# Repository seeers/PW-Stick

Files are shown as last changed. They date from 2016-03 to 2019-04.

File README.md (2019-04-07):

**[PW-Stick](https://github.com/seeers/PW-Stick)** is a easy to use hardware password manager
======

## Features
* Stores up to 9 user names and passwords / each up to 47 characters
* Keepass 2 (http://keepass.info/) supports the PW-Stick with a plugin
* AES Encrypted Memory
* Protected by a 4 digit pin
* Secure erase after 4 wrong pin attempts
* Optional auto lock timer
* Works as HID Keyboard

## Portable version
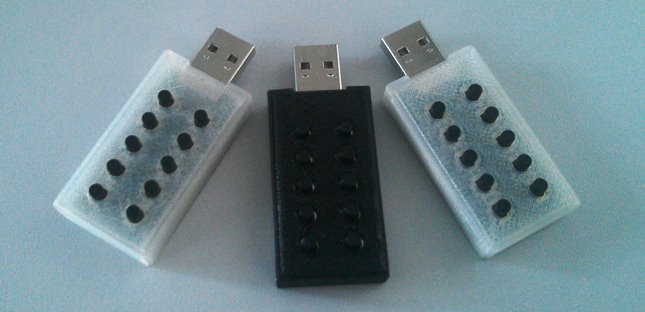
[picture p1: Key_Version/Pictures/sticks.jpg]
Stick


## Desktop version
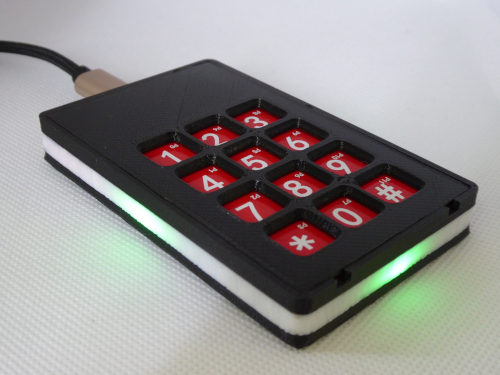
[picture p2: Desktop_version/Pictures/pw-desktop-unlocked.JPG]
Desktop


## Instructions

See the wiki for build and use instructions.

## Notes
**Released:** 
* Stick version by Seeers : Mar 23, 2016
* Desktop version by MatthGyver : Apr 07, 2019

**Status:** Operational, maybe some bugs, works for me since some months.

**Licence:**  CC BY-NC-SA 3.0

## Contact
**Point of Contact:**  
* Twitter: [@seeers0](https://twitter.com/seeers0)
* E-Mail: <seeers@gmx.de>

-----

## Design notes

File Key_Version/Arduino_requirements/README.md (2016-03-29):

## Arduino Version:
* arduino-1.0.5-r2

## Used Libraries:
* https://github.com/DavyLandman/AESLib
* https://github.com/adafruit/Adafruit_NeoPixel
* http://playground.arduino.cc/Code/Password

## Modified files
* \Arduino-1.0.5-r2\hardware\arduino\cores\arduino\HID.cpp
* \Arduino-1.0.5-r2\hardware\arduino\cores\arduino\USBAPI.h
* \Arduino-1.0.5-r2\hardware\arduino\cores\arduino\USBCore.h

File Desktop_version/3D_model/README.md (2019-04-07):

# Description
Bottom is composed of 3 pieces :
* bottom-a.stl
* bottom-b.stl
* bottom-c.stl

All this part are assembled in one with Slic3r as bottom.amf file.

I'm using a dual head printer but you should be able to do this with single head. There is some technics to change filament like [this](https://www.youtube.com/watch?v=vnbQ0YTZnmk). *I've not tested*

# Pictures
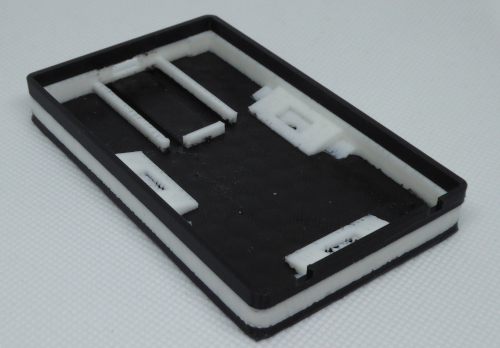
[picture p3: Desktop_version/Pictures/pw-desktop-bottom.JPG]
Bottom


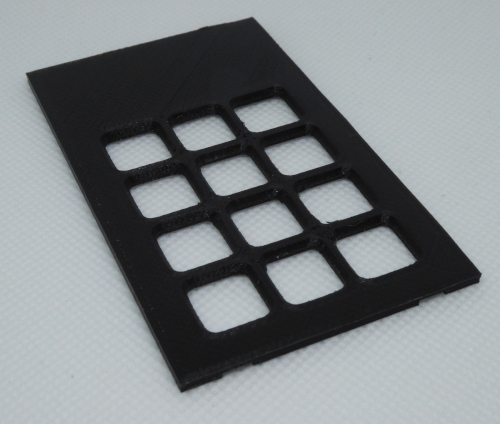
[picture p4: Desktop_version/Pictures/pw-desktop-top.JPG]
Top


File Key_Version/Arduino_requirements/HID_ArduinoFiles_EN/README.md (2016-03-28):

## Location:
**path_to_arduino**\Arduino-1.0.5-r2\hardware\arduino\cores\arduino

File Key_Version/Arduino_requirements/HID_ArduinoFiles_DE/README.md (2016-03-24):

## Location:
**path_to_arduino**\Arduino-1.0.5-r2\hardware\arduino\cores\arduino

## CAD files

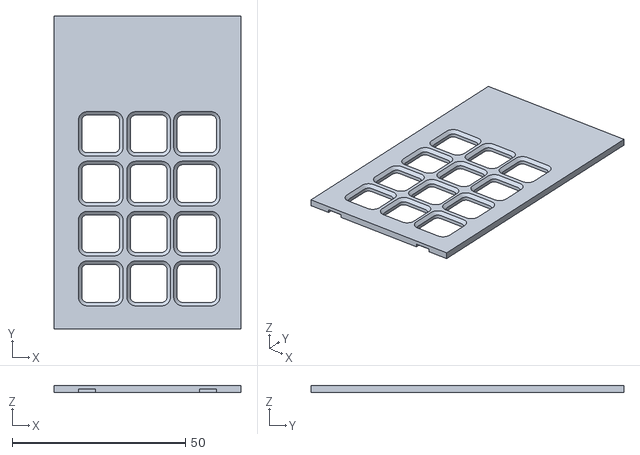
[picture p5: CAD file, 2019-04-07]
Desktop_version/3D_model/top.STL
53.9 x 90.2 x 2.10

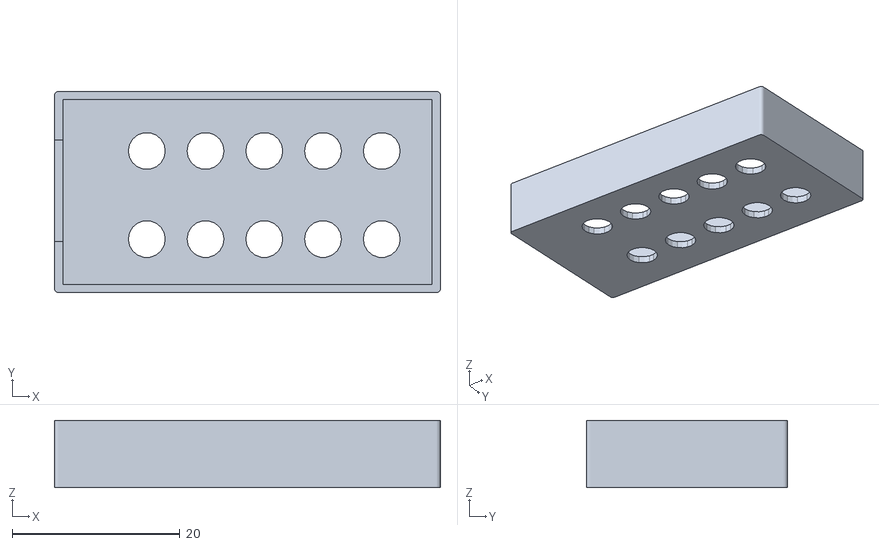
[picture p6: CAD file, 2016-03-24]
Key_Version/3D_PrintedCase/PW_Stick_top.stl
46.0 x 24.0 x 8.00

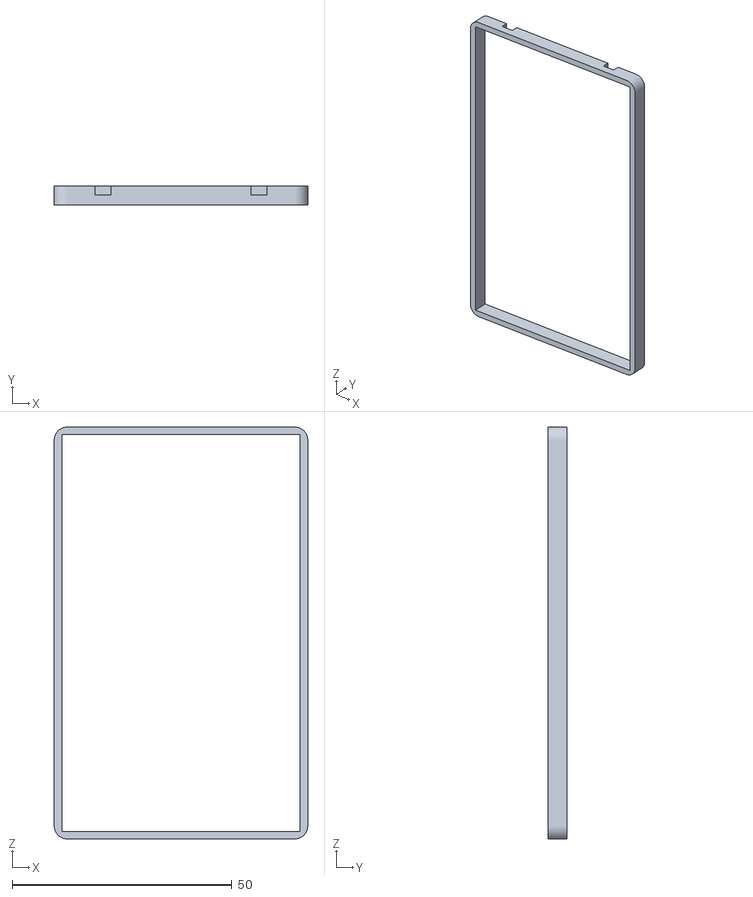
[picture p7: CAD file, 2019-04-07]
Desktop_version/3D_model/bottom-c.STL
57.7 x 4.30 x 93.8

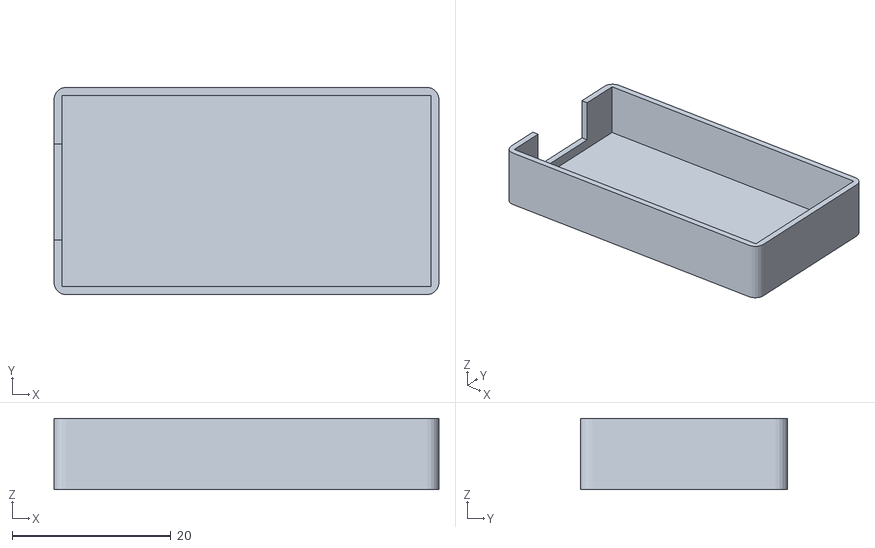
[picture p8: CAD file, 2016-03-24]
Key_Version/3D_PrintedCase/PW_Stick_bottom.stl
48.5 x 26.1 x 9.00

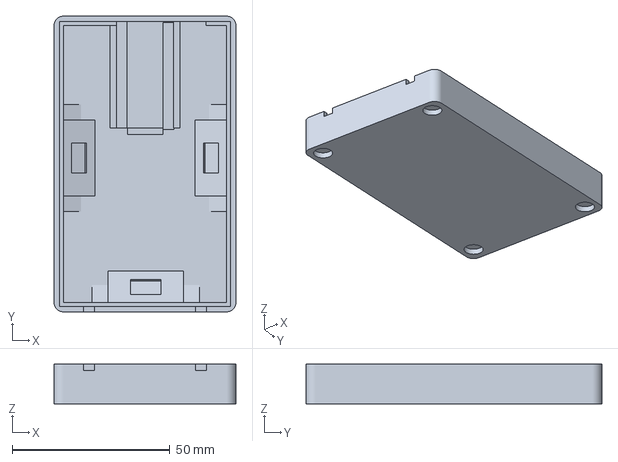
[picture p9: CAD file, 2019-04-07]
Desktop_version/3D_model/bottom.amf
57.7 x 93.8 x 12.6 mm

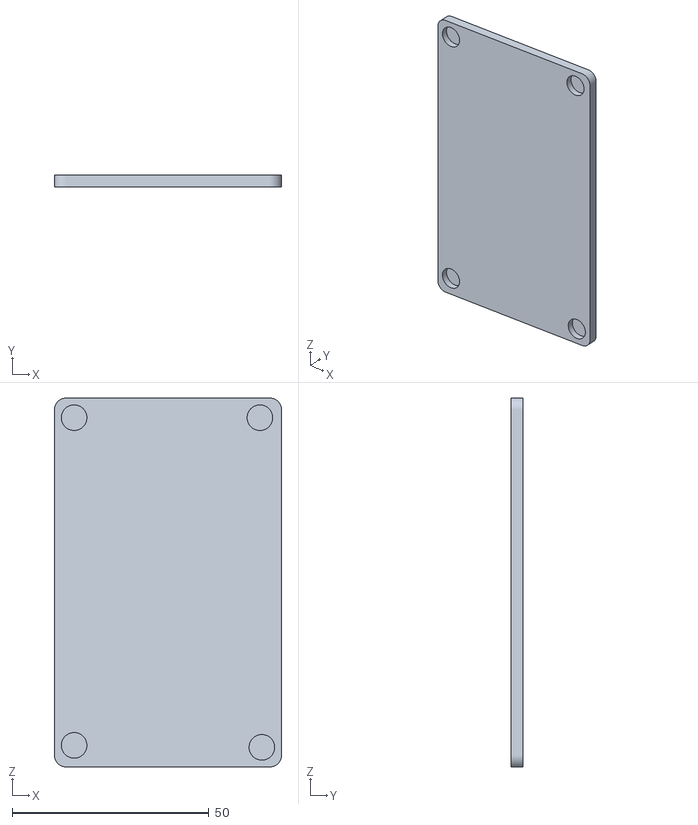
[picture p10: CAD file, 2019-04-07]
Desktop_version/3D_model/bottom-a.STL
57.7 x 3.00 x 93.8

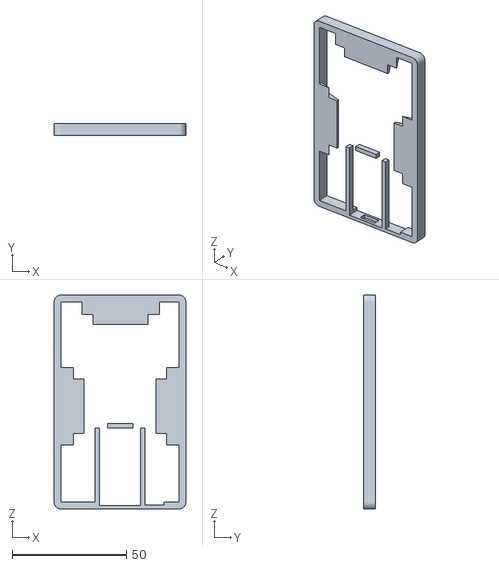
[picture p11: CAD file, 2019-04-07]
Desktop_version/3D_model/bottom-b.STL
57.7 x 5.40 x 93.8

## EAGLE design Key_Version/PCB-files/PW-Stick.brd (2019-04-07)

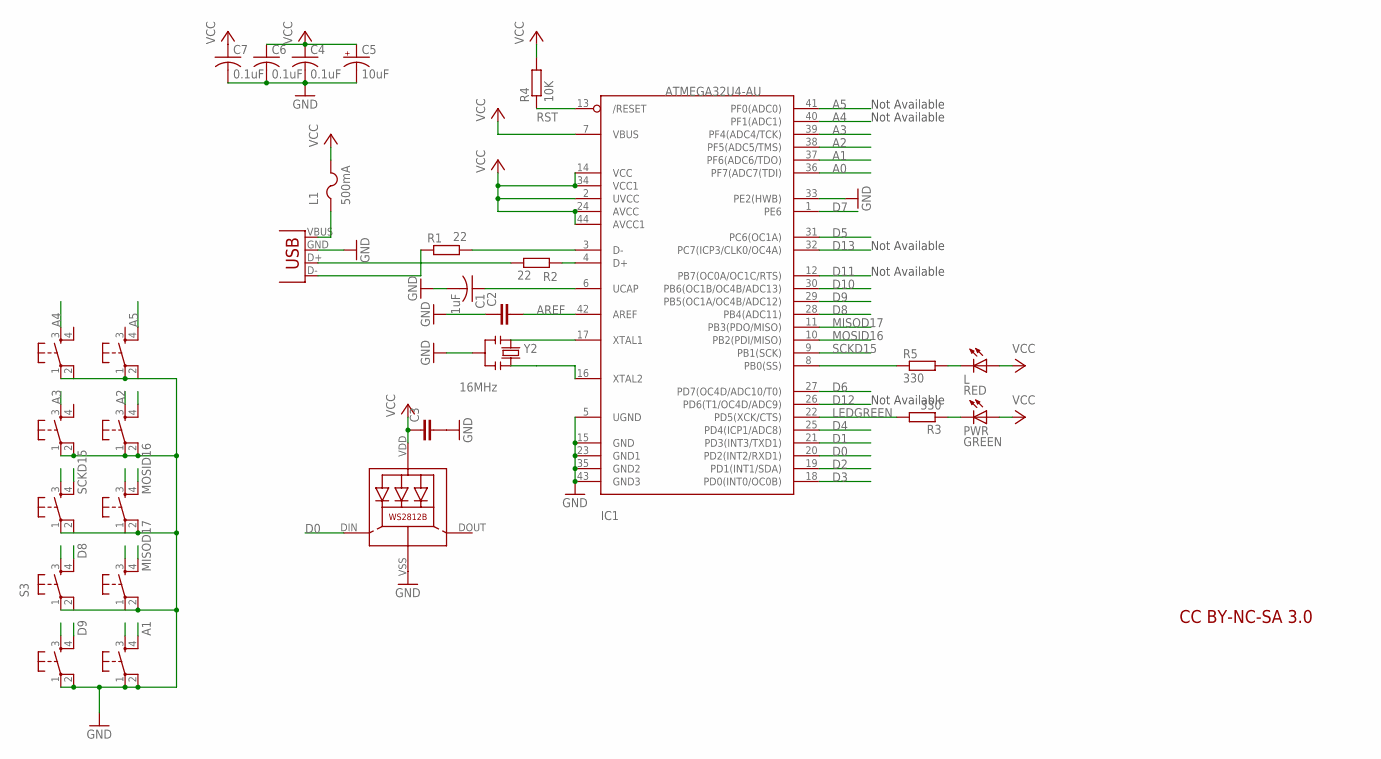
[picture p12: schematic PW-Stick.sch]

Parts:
C1: 1uF; C0805K
C2, C3: C-EUC0805; C0805
C4, C6, C7: 0.1uF; C0805K
C5: 10uF; A/3216-18R
IC1: ATMEGA32U4-AU; TQFP44
JP2: USB-A-H
L: RED; CHIPLED_0805
L1: 500mA; R1206
LED1: WS2812B
PWR: GREEN; CHIPLED_0805
R1, R2: 22; R0805
R3, R5: 330; R0805
R4: 10K; R0805
S1, S2, S3, S4, S5, S6, S7, S8, S9, S10: DTSM-6
Y2: 16MHz; RESONATOR

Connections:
A0: IC1.36 (PF7(ADC7(TDI))
A1: IC1.37 (PF6(ADC6/TDO)), S2.4
A2: IC1.38 (PF5(ADC5/TMS)), S8.3
A3: IC1.39 (PF4(ADC4/TCK)), S7.3
A4: IC1.40 (PF1(ADC1)), S9.3
A5: IC1.41 (PF0(ADC0)), S10.4
AREF: C2.2, IC1.42 (AREF)
D0: IC1.20 (PD2(INT2/RXD1)), LED1.DIN (DI)
D1: IC1.21 (PD3(INT3/TXD1))
D2: IC1.19 (PD1(INT1/SDA))
D3: IC1.18 (PD0(INT0/OC0B))
D4: IC1.25 (PD4(ICP1/ADC8))
D5: IC1.31 (PC6(OC1A))
D6: IC1.27 (PD7(OC4D/ADC10/T0))
D7: IC1.1 (PE6)
D8: IC1.28 (PB4(ADC11)), S3.4
D9: IC1.29 (PB5(OC1A/OC4B/ADC12)), S1.4
D10: IC1.30 (PB6(OC1B/OC4B/ADC13))
D11: IC1.12 (PB7(OC0A/OC1C/RTS))
D12: IC1.26 (PD6(T1/OC4D/ADC9))
D13: IC1.32 (PC7(ICP3/CLK0/OC4A))
GND: C1.2, C2.1, C3.2, C4.2, C5.-, C6.2, C7.2, IC1.5 (UGND), IC1.15 (GND), IC1.23 (GND1), IC1.33 (PE2(HWB)), IC1.35 (GND2), IC1.43 (GND3), JP2.GND (VBUS), LED1.VSS (GND), S1.1, S1.2, S2.1, S2.2, S3.1, S4.2, S5.1, S6.2, S7.1, S7.2, S8.1, S8.2, S9.1, S10.1, Y2.2
LEDGREEN: IC1.22 (PD5(XCK/CTS)), R3.2
MISOD17: IC1.11 (PB3(PDO/MISO)), S4.4
MOSID16: IC1.10 (PB2(PDI/MISO)), S6.3
unnamed: PWR.C, R3.1
unnamed: JP2.D+ (D-), R2.1
unnamed: IC1.3 (D-), R1.2
unnamed: IC1.4 (D+), R2.2
unnamed: JP2.D- (D+), R1.1
unnamed: IC1.8 (PB0(SS)), R5.1
unnamed: L.C, R5.2
unnamed: IC1.17 (XTAL1), Y2.1
unnamed: IC1.16 (XTAL2), Y2.3
unnamed: C1.1, IC1.6 (UCAP)
RST: IC1.13 (/RESET), R4.1
SCKD15: IC1.9 (PB1(SCK)), S5.3
VBUS: JP2.VBUS (GND), L1.1
VCC: C3.1, C4.1, C5.+, C6.1, C7.1, IC1.2 (UVCC), IC1.7 (VBUS), IC1.14 (VCC), IC1.24 (AVCC), IC1.34 (VCC1), IC1.44 (AVCC1), L.A, L1.2, LED1.VDD, PWR.A, R4.2

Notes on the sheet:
CC BY-NC-SA 3.0
Not Available

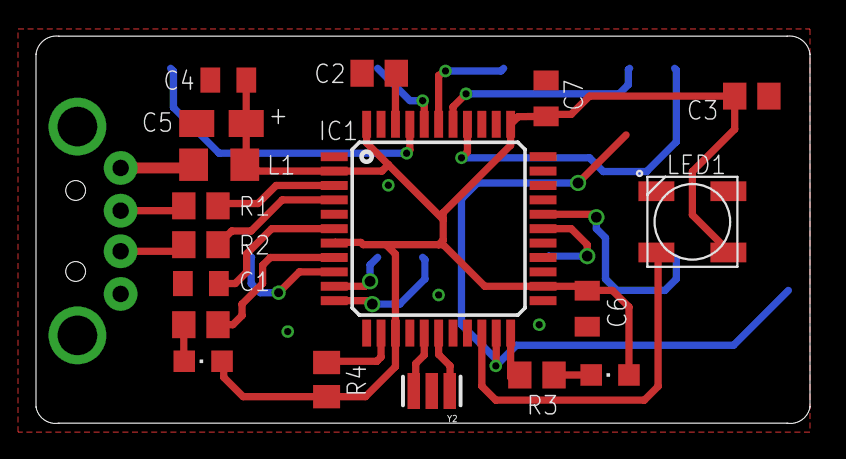
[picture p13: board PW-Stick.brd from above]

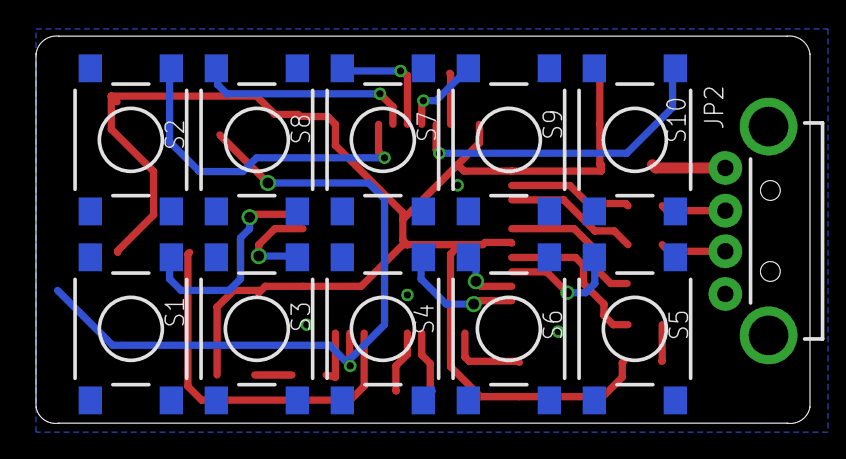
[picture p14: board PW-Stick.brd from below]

Board: 2 copper layers, 43.0 x 21.5 mm, 29 parts (11 on the bottom side), 27 nets.

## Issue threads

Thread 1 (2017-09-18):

[Request]Schematic source file

matthgyver, 2017-09-18:
Hi,

Your project seem very interresting.
I just buy an Arduino Leonardo to try it but I plan to build one from scratch.
Could you publish the source of the electronic schematic and / or the PCB layer please ?

Thank you

seeers, 2017-09-20:
Hi,
yes of course:
[PW-StickPublic.zip](https://github.com/seeers/PW-Stick/files/1318209/PW-StickPublic.zip)

matthgyver, 2017-09-20:
Hi,
Thank you very much.
I see that there is no value for C2 and C3. What do you recommend please ?
On the way, where did you get your printed circuit boards ?

seeers, 2017-09-20:
You're welcome. C2 and C3 are 100n
I got my Boards from https://www.itead.cc/open-pcb/pcb-prototyping.html

matthgyver, 2017-09-20:
Price look good and the finish too when I see your pictures.
What is the height of your microswitch to go with the 3D printed case please  ? (I prepare my shopping list)

matthgyver, 2017-12-29:
I've take this one : https://fr.aliexpress.com/item/Free-Shipping-100pcs-Tact-Switch-DIP-type-6x6X8-mm-Tactile-Switch/866454082.html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
It's 6x6x8mm and fit nice

Closed 2017-12-29.

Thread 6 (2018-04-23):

AESLib related IDE error

tinker4545, 2018-04-23:
Thx seers for your work, i have a problem, im getting error codes relating to AESLib (see below)
Ive tried arduino 1.0.4 aswell as 1.0.5-r2.
What is the 'HardwarePWManager.v12.suo' ? do i need to do anything with this file?
Many thanks

Documents\Arduino\libraries\AESLib\AESLib.c: In function 'aes128_enc_multiple':
Documents\Arduino\libraries\AESLib\AESLib.c:75: error: 'for' loop initial declaration used outside C99 mode
\Documents\Arduino\libraries\AESLib\AESLib.c: In function 'aes256_enc_multiple':
\Documents\Arduino\libraries\AESLib\AESLib.c:95: error: 'for' loop initial declaration used outside C99 mode
\Documents\Arduino\libraries\AESLib\AESLib.c: In function 'aes128_dec_multiple':
Documents\Arduino\libraries\AESLib\AESLib.c:213: error: 'for' loop initial declaration used outside C99 mode
Documents\Arduino\libraries\AESLib\AESLib.c: In function 'aes256_dec_multiple':
\Documents\Arduino\libraries\AESLib\AESLib.c:233: error: 'for' loop initial declaration used outside C99 mode

matt i moved it over to here, cheers

matthgyver, 2018-04-23:
Hi,
I've problem with Arduino version > 1.0.5 but it's not the same (error on keyboard.h).
I've not this error but I'm on Linux and the compiler or compilation setting are maybe different.
Try to modifiy de lib file like as described here : https://stackoverflow.com/questions/24881/how-do-i-fix-for-loop-initial-declaration-used-outside-c99-mode-gcc-error
(Extract the i variable declaration from the loop)

For the suo file, google give me the response : https://fileinfo.com/extension/suo

tinker4545, 2018-04-23:
matt ur a star! i followed the links and finally got it to compile :-) I edited the .h file :-) 1st time doing it lol

another question for you if you dont mind, im putting together seers prototype version using a full pro micro, looking at the schematic i will need other components, can you tell what ones I need? I got the buttons soldered and ready and the WS2812b is in the mail.

matthgyver, 2018-04-23:
You just need buttons and WS2812b.
Take a look into the "desktop version" folder. I'm using only a full pro micro, switch and LED.
Source code is for the final version so you'll modify it for define PIN correctly I think.
Schematic is for building from scratch.

tinker4545, 2018-04-23:
ah i see, no wonder i was confused a little, makes sense now. il look at the desktop version later.

thanks again for your help (i was gonna give up this project)

matthgyver, 2018-04-24:
You'r welcome

Closed 2018-04-24.

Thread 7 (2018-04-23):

Arduino requirement question

matthgyver, 2018-04-23:
Hi Seeers,

I'm trying to update your code to do a project for [PlateformIO](https://platformio.org/).
This IDE is free, light and powerfull.
It use a latest version of Arduino core so I should update this files :
- USBAPI.h
- USBCore.cpp

Since your work, lot of thing have changed.
Did you remember the adaptation that you made ? It help me to update the code.

Thank you

Closed 2018-09-11.

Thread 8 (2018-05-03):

UK keyboard layout

tinker4545, 2018-05-03:
Hi Seers,
Can you help me out with a small problem, i got everything running but the keyboard layout is US i need a UK layout, ive been trying to change it in the HID.cpp but got all mixed up, is there a way to change it all at once?
Thanks,  great project btw

matthgyver, 2019-05-11:
Hi Tinker,

Keyboard layout on Arduino is'nt simple :-/ There's no library like the Teensy board have by exemple.

I needed French Azerty layout and don't found anything working great so I build my own : https://github.com/matthgyver/Arduino-Keyboard-FR

Maybe you could build your own. This link helped me :
* https://raw.githubusercontent.com/qlyoung/armory-keyboard/master/layouts/keyboard-layout.png
* https://www.ascii-code.com/

Closed 2019-05-11.

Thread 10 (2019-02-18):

Plugins problems with linux ( keepass 2.38 ) + pinout misunderstood

Debian-10, 2019-02-18:
Hello and thanks again for providing this github !

I installed Keepass 2.38 with ubuntu repositories ( it uses mono ). I copied the PWstick.dll plugin into the correct path. When i restart KeePass , i have " non compatible plugin ". The thing I don't understand is that it works like a charm on windows with the same keepass version. I installed mono-complete. Any ideas ?

When reading the .ino code , I don't understand where is A5 pin and strange that you can only have 8 buttons ( most strange fact is that they're soldered by two ports and not like casual : to port and to GND )
That's maybe not best explaination ( I'm French :D )

Debian-10

Debian-10, 2019-05-09:
After reading more the code and searched more about arduino, i found solution for buttons.

matthgyver, 2019-05-11:
Salut,

Désolé de ne pas avoir répondu, je ne reçois pas de notifications sur les issues (faut que je regarde de plus près).

Pour Mono je ne peux pas te répondre, je n'ai pas testé. J'aimerais une solution plus universelle que Keepass car çle plugin ne fonctionne que sous windows mais je n'ai pas les connaissances pour développer quelque chose :-/

Concernant le cablage je n'ai pas bien saisi ce que tu veux dire désolé.

Closed 2019-05-09.

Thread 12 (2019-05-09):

Problem with the plugin on windows

Debian-10, 2019-05-09:
Hello again,
As i'm still trying to get this working, i successfully burned the code into my arduino pro-micro.
I have keepass 2.41 installed on my computer and put the pwkeeper.dll plugin in the plugin/ folder.
I connect it to windows, I type the default password ' 0000 ' and unlocked the key but when trying to change settings of the key or reading its data, i always have ' No key found '.
when i press "0" button on my key, it locks the computer like it should do.
I precise that i already tried on another computer.
Thanks again for this recent update !

Debian-10

tinker4545, 2019-05-09:
The Plugin is compiled for KeePass 2.32

Debian-10, 2019-05-10:
> The Plugin is compiled for KeePass 2.32

Regarding the wiki , the plugin works on 2.41 too.

tinker4545, 2019-05-10:
Ah ur right im on the old version, try 2.32 anyways just to see

Debian-10, 2019-05-11:
What is your version of keepass when the plugin work for you ?

matthgyver, 2019-05-11:
Hi,

It's work with the last version of Keepass (a friend have tested recently).

Have you installed the Arduino IDE on your windows ? It act as a "driver" and it's needed to configure the stick with Keepass. *(only for configure it, you can use it on any computer without IDE)*

What version did you use ? (stik or desktop)

Debian-10, 2019-05-11:
Hello, i have the arduino ide on my computer.
The most strange fact is that i tested the key month ago and it worked but now not . ( Even with same arduino version and same keepass )

Debian-10, 2019-05-11:
I don't understand at all , i previously reinstalled the arduino ide but i did it now again and it works. But for how many time ?

tinker4545, 2019-05-11:
> s

2.32   anyways glad u got it working

matthgyver, 2019-05-12:
Strange. Maybe due to system update.

Debian-10, 2019-05-12:
So now , if I want to connect my key with keepass on another computer, should I install arduino on it ?

matthgyver, 2019-05-12:
Yes.
Arduino IDE contain a driver that allow serial communication between computer and Arduino.
Maybe driver installation (https://www.arduino.cc/en/Guide/DriverInstallation) is enougth. I have'nt tested.

Debian-10, 2019-05-12:
Thanks a lot for help !

Closed 2019-05-12.

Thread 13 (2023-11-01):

BOM in file

LoriVinyls, 2023-11-01:
Hello!

In BOM file no detailed specifications about each resistor\capacitor. I went to shop and they say i need to be more detail because with same resistance\capacitys there are few options to choose with different Watt's

Thank you

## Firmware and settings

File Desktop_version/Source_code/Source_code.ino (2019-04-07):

/*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
 Commercial use of this project is not allowed
 	
 Contact: seeers@gmx.de
 Desktop & Touch version : MatthGyver
  
 You need an old Arduino IDE because the keyboard emulation was different.
 With the recent Arduino, keyboard is'nt into the core and all library that
 I've tested don't support extended ASCII so don't work well for other langage that US.
 Original core code was modified by Seers to support them but only work with old Arduino vesion.

 Used Libraries:
 https://github.com/DavyLandman/AESLib
 https://github.com/adafruit/Adafruit_NeoPixel
 http://playground.arduino.cc/Code/Password
 https://bitbucket.org/teckel12/arduino-toneac/wiki/Home
 https://github.com/adafruit/Adafruit_MPR121


Buzzer connection like in the library documentation : pin 9 & 10
Keypad connection is in 2IC so :
  - SDA = Pin digital 2
  - SCL = Pin digital 3
  - IRQ = Not connected
 */

#include "cButton.h"
#include "Wire.h"
#include <EEPROM.h>
#include <Password.h>
#include "EEPROMAnything.h"
#include <Adafruit_NeoPixel.h>
#include <AESLib.h>
#include "Adafruit_MPR121.h"
#include <toneAC.h>

// #define DEBUG

// If you want that the device is unlock at start (usefull for tests)
#define LOCKED  'true'

// If DEVMODE = true, AES key is'nt regenerated so stored data is reachable after new burn
#define DEVMODE 'false'

// ----------------------------------------------------------------------------
// Set keyboard layout
// ----------------------------------------------------------------------------

// #define KEYBOARD_LAYOUT 'US'
#define KEYBOARD_LAYOUT 'FR'

#if KEYBOARD_LAYOUT == 'FR'
#include <KeyboardFR.h>
#else
#include <Keyboard.h>
#endif
// ----------------------------------------------------------------------------

#define LED_PIN                   5    //LED
#define NUM_LED                   3    //Number of LED

#define DEFAULT_LONGPRESS_LEN    25  // Min nr of loops for a long press
#define DELAY                    20  // Delay per loop in ms - orig 20

#define buttoncount				10

//////////////////////////////////////////////////////////////////////////////
//EEPROM
#define Get_All_EEPROM        0x40  
#define WriteACC1             0x41  
#define WriteACC2             0x42   
#define WriteACC3             0x43   
#define WriteACC4             0x44   
#define WriteACC5             0x45
#define WriteACC6             0x46
#define WriteACC7             0x47
#define WriteACC8             0x48
#define WriteACC9             0x49
//#define WriteACC10            0x50
#define LockDevice			  0x33
#define ChangePin             0x34
#define IsReady               0x35
#define ERASE                 0x36
#define GetVersion            0x37
#define LearnIRBtn			  0x38
#define SendKeyDebug		  0x39
#define ReadConfig			  0x60
#define WriteConfig			  0x61
#define GetRawEEProm		  0x66
#define UserDoneByte          0x02
#define PWDoneByte			  0x03
#define EOTByte				  0x04

#define EEGlobalEnter		  960
#define EELockWSTime		  961
#define EELockWS_WIN_L		  962

#define DoneMessage          "þDONE"
#define Version				 "2.0"

// Define LED colours
uint8_t LEDGreen[3] = { 0,90,0 };
uint8_t LEDOrange[3] = { 50,30,0 };
uint8_t LEDBlue[3] = { 0,0,90 };
uint8_t LEDRed[3] = { 90,0,0 };
uint8_t LEDOff[3] = { 0,0,0 };
// uint8_t LockLEDcolor[3] = { 0,0,0 };
uint8_t LockLEDcolor[3] = { 50,30,0 };

// Define sound On/Off
boolean soundOn = true;
int soundVolume = 5;

// Mapping keyboard touch (not usable for pin code but simplify code in main loop)
int keyMap[12] = { 1,4,7,100,2,5,8,0,3,6,9,200 };

// You can have up to 4 on one i2c bus but one is enough for testing!
Adafruit_MPR121 cap = Adafruit_MPR121();

int was_pressed = 0;
int now_pressed = 0;
uint8_t longPressCount = 0;

// Delay between print keyboard char (in ms)
int keyboardDelay = 30;

typedef struct
{
  char User[48];
  char PW[48];
  byte enter;
} 
UserPW_t;

char Pin[5];

uint8_t	    byteCount = 0; // reveived bytes
uint8_t     writeCount = 0;
byte        gRxBuffer[100];   // Receive Buffer
byte		b;
byte		settings[3];

uint8_t pressed_counter = 0;
uint8_t longpress_len = 25;

UserPW_t users[buttoncount-1];
Adafruit_NeoPixel rgbled = Adafruit_NeoPixel(NUM_LED, LED_PIN, NEO_GRB + NEO_KHZ800);
byte value;

boolean userdone = false;
boolean pwdone = false;
boolean startwrite = true;
boolean locked = true;
boolean locktimer = false;
boolean shiftmode = false;
boolean GlobalReturn = false;
boolean LockWorkstation = false;
byte	wrongPinCount = 0;
unsigned long lockaftertime = 0;
unsigned long unlocktime = 0;

Password password = Password("0000");

aes_context ctx;

// If DEVMODE = false, the key is generated randomly
# if DEVMODE == 'true'
uint8_t iv[] = { 124, 163, 83, 45, 67, 234, 203, 41, 145, 68, 58, 72, 85, 13, 94, 87 };
uint8_t key[16] = { 64, 26, 2, 3, 42, 5, 112, 84, 8, 9, 234, 198, 12, 89, 137, 15 };
#else
uint8_t i1  = rand() %256;
uint8_t i2  = rand() %256;
uint8_t i3  = rand() %256;
uint8_t i4  = rand() %256;
uint8_t i5  = rand() %256;
uint8_t i6  = rand() %256;
uint8_t i7  = rand() %256;
uint8_t i8  = rand() %256;
uint8_t i9  = rand() %256;
uint8_t i10 = rand() %256;
uint8_t i11 = rand() %256;
uint8_t i12 = rand() %256;
uint8_t i13 = rand() %256;
uint8_t i14 = rand() %256;
uint8_t i15 = rand() %256;
uint8_t i16 = rand() %256;

uint8_t iv[] = { i1,i2,i3,i4,i5,i6,i7,i8,i9,i10,i11,i12,i13,i14,i15,i16 };

uint8_t k1  = rand() %256;
uint8_t k2  = rand() %256;
uint8_t k3  = rand() %256;
uint8_t k4  = rand() %256;
uint8_t k5  = rand() %256;
uint8_t k6  = rand() %256;
uint8_t k7  = rand() %256;
uint8_t k8  = rand() %256;
uint8_t k9  = rand() %256;
uint8_t k10 = rand() %256;
uint8_t k11 = rand() %256;
uint8_t k12 = rand() %256;
uint8_t k13 = rand() %256;
uint8_t k14 = rand() %256;
uint8_t k15 = rand() %256;
uint8_t k16 = rand() %256;

uint8_t key[16] = { k1,k2,k3,k4,k5,k6,k7,k8,k9,k10,k11,k12,k13,k14,k15,k16 };
#endif

// ----------------------------------------------------------------------------
// Setup
// ----------------------------------------------------------------------------
void setup()
{ 
  Keyboard.begin();
  rgbled.begin();
  rgbled.show();
  
#if LOCKED == 'false'
  locked = false;
#else
  locked = true;
#endif

  LEDcolor(LockLEDcolor);
  EEPROM_readAnything(1000, Pin);

  if (isValidNumber(Pin))
    password = Password(Pin);
  else
    password = Password("0000");

  wrongPinCount = EEPROM.read(950);

  ReadConfigSettings();

  Serial.begin(9600);
  
  cap.begin(0x5A);
}

// ----------------------------------------------------------------------------
// Read configuration function
// ----------------------------------------------------------------------------
void ReadConfigSettings()
{
  settings[0] = EEPROM.read(EEGlobalEnter);
  settings[1] = EEPROM.read(EELockWSTime);
  settings[2] = EEPROM.read(EELockWS_WIN_L);

  if (settings[0] != 0)
    GlobalReturn = true;
  else
    GlobalReturn = false;

  if (settings[1] != 0)
  {		
    locktimer = true;
    lockaftertime = settings[1];
    lockaftertime = lockaftertime * 1000;
    lockaftertime = lockaftertime * 60;
  }

  if (settings[2] != 0)
    LockWorkstation = true;
  else
    LockWorkstation = false;
  
}

// ----------------------------------------------------------------------------
// Write configuration function
// ----------------------------------------------------------------------------
void writeConfigToEEprom()
{

  if (startwrite == true)
  {
    //Serial.println("Clear Pin Object...");
    for (int i = 0; i < 3; i++){
      settings[i] = 0;
    }		
    startwrite = false;
  }

  gRxBuffer[byteCount] = b;
  byteCount++;

  if (b == EOTByte)
  {
    Serial.print("Enter:");
    Serial.print(settings[0]);
    Serial.print("Lock:");
    Serial.print(settings[1]);
    Serial.print("LockWS:");
    Serial.print(settings[2]);

    EEPROM.write(EEGlobalEnter, settings[0]);
    EEPROM.write(EELockWSTime, settings[1]);
    EEPROM.write(EELockWS_WIN_L, settings[2]);

    Serial.print(DoneMessage);
    byteCount = 0;
    unlocktime = millis();
    ReadConfigSettings();
    return;
  }
  //	Serial.print("Config");
  //	Serial.println(writeCount);
  //	Serial.println(b);
  settings[writeCount] = b;
  writeCount++;
}

// ----------------------------------------------------------------------------
// Play sound function. Used when long key press
// ----------------------------------------------------------------------------
void long_key_sound(){
  toneAC(4500,soundVolume,100);
}

// ----------------------------------------------------------------------------
// Play sound function. Used when short key press
// ----------------------------------------------------------------------------
void short_key_sound(){
  toneAC(1700,soundVolume,100);
}

// ----------------------------------------------------------------------------
// Play sound function. Used when pin code is wrong
// ----------------------------------------------------------------------------
void wrong_sound(){
  toneAC(300,soundVolume,200);
  toneAC(150,soundVolume,200);
}

// ----------------------------------------------------------------------------
// Play sound function. Used when pin code is OK and device unlock
// ----------------------------------------------------------------------------
void unlock_sound(){
  toneAC(3000,soundVolume,100);
  toneAC(3500,soundVolume,100);
}

// ----------------------------------------------------------------------------
// Play sound function. Used when lock device
// ----------------------------------------------------------------------------
void lock_sound(){
  toneAC(3500,soundVolume,100);
  toneAC(3000,soundVolume,100);
}

// ----------------------------------------------------------------------------
// LED function. Set same color for all LEDs
// ----------------------------------------------------------------------------
void LEDcolor( uint8_t LEDparam[] ){
  uint8_t LEDnum;
  for ( LEDnum = 0; LEDnum < NUM_LED; LEDnum ++){
    rgbled.setPixelColor(LEDnum,LEDparam[0],LEDparam[1],LEDparam[2]);
  }
  rgbled.show();
}

// ----------------------------------------------------------------------------
// LED function. Blink LED. Alternate LED color and LED off
// ----------------------------------------------------------------------------
void FlashLED( uint8_t initColor[], uint8_t flashColor[], uint8_t flashDelay, uint8_t flashNb){
  uint8_t flashCount;

  for ( flashCount = 0; flashCount <= flashNb; flashCount ++){
    LEDcolor(LEDOff);
    delay(flashDelay);
    LEDcolor(flashColor);
    delay(flashDelay);
  }

  LEDcolor(initColor);
}

// ----------------------------------------------------------------------------
// Main loop
// ----------------------------------------------------------------------------
void loop()
{
  if (locked == true) {

    InputPin();

    if(password.evaluate())
    {
      Serial.println("PW OK!");
      if ( soundOn == true ) { unlock_sound(); }
      if (wrongPinCount != 0)
      {
        wrongPinCount = 0;
        EEPROM.write(950,0);
        Serial.println("Write EEprom wrongPinCnt = 0");
      }
      Serial.flush();
      LEDcolor(LEDGreen);

      unlocktime = millis();
      
      locked = false;
      for (int i=0; i < buttoncount-1; i++)
      {				
        EEPROM_readAnything(i*97,users[i]);
      }
      was_pressed = 0;
    }
    else
    {
      //WRONG PIN!!!!!!!!
      if ( soundOn == true ) { wrong_sound(); }
      FlashLED(LEDOrange, LEDRed, 200, 4);
      password.reset();
      wrongPinCount++;

      if (wrongPinCount > 3)
      {
        Serial.println("format EEPROM...");
        FormatEEProm();
        wrongPinCount = 0;
      }
      else
      {
        Serial.print("write EEprom wrongPinCnt = ");
        Serial.println(wrongPinCount);
        EEPROM.write(950, wrongPinCount);
      }
    }
  }
  else
  {  
    if (locktimer == true && millis() - unlocktime > lockaftertime) {
      locked=true;
      password.reset();
      if ( soundOn == true ) { lock_sound(); }
      LEDcolor(LockLEDcolor);      
    }

    serialstuff();
    // **************************
    now_pressed = cap.touched();
    for (uint8_t i = 0; i < 12; i ++) {
      if ( now_pressed & _BV(3) || now_pressed & _BV(7) || now_pressed & _BV(11) ){
        if (LockWorkstation == true){ lockWindows() ; }
        locked=true;
        LEDcolor(LockLEDcolor);
        if ( soundOn == true ) { lock_sound(); }
        password.reset();
        break;
      }else{
        if ( ( !(now_pressed & _BV(i) ) && (was_pressed & _BV(i) ) ) && ( pressed_counter < longpress_len ) ){
          if ( soundOn == true ) { short_key_sound(); }
          unlocktime = millis();
          PrintUserPW(keyMap[i]);
          FlashLED(LEDGreen, LEDGreen, 50, 2);
        }else if ( (now_pressed & _BV(i)) && (pressed_counter == longpress_len ) ){
          if ( soundOn == true ) { long_key_sound(); }
          FlashLED(LEDGreen, LEDGreen, 100, 3);
          unlocktime = millis();
          PrintPW(keyMap[i]);
        }
      }
    }

    if ( now_pressed ){
      pressed_counter ++;
    }else{
      pressed_counter = 0;
    }
    
    was_pressed = now_pressed;

    delay(DELAY);

#ifdef DEBUG
    Serial.print(F("FREEMEM: ")); 
    Serial.println(freeRam ());
#endif
  }
}

// ----------------------------------------------------------------------------
// Function to evaluate PIN code
// ---------------------------------------------------------------------------- 
void InputPin() {
  value = 0;
  int i = 0;
  while ( i < 4){   // request 4 digits
    do {
      serialLockedstuff();
      delay(100);
    }
    while ( ! (cap.touched()) );
    
    now_pressed = cap.touched();
    for (uint8_t k = 0; k < 12; k ++) {
      if ( now_pressed & _BV(k) ) {      
        if ( soundOn == true ) { short_key_sound(); }
        FlashLED(LEDOrange, LEDOrange, 50, 1);
        switch(k){
          case 0 :
            password.append('1');
            break;
          case 1 :
            password.append('4');
            break;
          case 2 :
            password.append('7');
            break;
          case 4 :
            password.append('2');
            break;
          case 5 :
            password.append('5');
            break;
          case 6 :
            password.append('8');
            break;
          case 7 :
            password.append('0');
            break;
          case 8 :
            password.append('3');
            break;
          case 9 :
            password.append('6');
            break;
          case 10 :
            password.append('9');
            break;
          default :
            password.append('a');
        }
        i ++;
      }
    }
  }
}

// ----------------------------------------------------------------------------
// Function for serial messages when device is locked
// ----------------------------------------------------------------------------
void serialLockedstuff() 
{

  while (Serial.available())
  {
    b = Serial.read();

    if ((byteCount == 0) && (b == 0xFE))   gRxBuffer[byteCount++] = b;  // first header byte 
    else if ((byteCount == 1) && (b == 0xFE))   gRxBuffer[byteCount++] = b;  // 2nd header byte
    else if (byteCount == 2)
    {
      writeCount = 0;
      userdone = false;
      pwdone = false;
      startwrite = true;
      if ((b == IsReady) || (b == ERASE) || (b == GetVersion) || (b == LearnIRBtn) || (b == SendKeyDebug))
      {
        gRxBuffer[byteCount++] = b;
      }
      else
      {
        Serial.print("locked...");
        Serial.print(DoneMessage);
        Serial.flush();
        byteCount = 0;
      }
    }
    else if (byteCount > 2)
    {
      switch (gRxBuffer[2])
      {
      case IsReady:
        Serial.print("locked...");
        Serial.print(DoneMessage);
        byteCount = 0;
        break;
      case ERASE:
        FormatEEProm();
        byteCount = 0;
        break;
      case GetVersion:
        printVersion();
        byteCount = 0;
        break;
      case SendKeyDebug:
        Serial.print("Sending HID: ");
        Serial.println(b,HEX);
        Keyboard.press(b);
        Keyboard.press('l');
        delay(100);
        Keyboard.releaseAll();
        byteCount = 0;
        break;
      default:
        Serial.print("locked...");
        Serial.print(DoneMessage);
        Serial.flush();
        byteCount = 0;

      }

    }

  }
}

// ----------------------------------------------------------------------------
// Function to tap login/password char by char with delay between them
// ----------------------------------------------------------------------------
void keyboardModifier( char *stringToModify ){
  for ( int i = 0; i < strlen(stringToModify); i++ ){
    Keyboard.print(stringToModify[i]);
    delay(keyboardDelay);
  }
}

// ----------------------------------------------------------------------------
// Function to tap password only
// ----------------------------------------------------------------------------
void PrintPW(int i)
{
  // i - 1 for mapping key / password entry match
  i = i - 1;

  EEPROM_readAnything(i * 97, users[i]);
  ctx = aes128_cbc_dec_start(key, iv);
  aes128_cbc_dec_continue(ctx, users[i].PW, 48);
  aes128_cbc_dec_finish(ctx);

  ctx = aes128_cbc_dec_start(key, iv);
  aes128_cbc_dec_continue(ctx, users[i].User, 48);
  aes128_cbc_dec_finish(ctx);


  keyboardModifier(users[i].PW);

  if ((users[i].enter == true) || (GlobalReturn == true)){
      Keyboard.write(10);
  }
  
}

// ----------------------------------------------------------------------------
// Function to tap login, tabulation and password
// ----------------------------------------------------------------------------
void PrintUserPW(int i)
{
  // i - 1 for mapping key / password entry match
  i = i - 1;

#ifdef DEBUG
  Serial.print("encrypted:");
  Serial.println(users[i].PW);
  Serial.println(users[i].User);
#endif

  EEPROM_readAnything(i * 97, users[i]);
  ctx = aes128_cbc_dec_start(key, iv);
  aes128_cbc_dec_continue(ctx, users[i].PW, 48);
  aes128_cbc_dec_finish(ctx);

  ctx = aes128_cbc_dec_start(key, iv);
  aes128_cbc_dec_continue(ctx, users[i].User, 48);
  aes128_cbc_dec_finish(ctx);

#ifdef DEBUG
  Serial.print("decrypted:");
  Serial.println(users[i].PW);
  Serial.println(users[i].User);
#endif

  if (users[i].User[0] != 0x00 && users[i].User[0] != 0x40 && users[i].User[0] != 0x21 && users[i].User[0] != 0x24)
  {
    keyboardModifier(users[i].User);
    Keyboard.write(9);
  }

  if (users[i].User[0] == 0x21) //!
  {
    sendAltCTRLDel();
    delay(1000);
  }
  if (users[i].User[0] == 0x24) //$
  {
    startRun();
    delay(300);
  }

  keyboardModifier(users[i].PW);
  if ((users[i].enter == true) || (users[i].User[0] == 0x40) || (GlobalReturn == true) || (users[i].User[0] == 0x24) || (users[i].User[0] == 0x21))
  {
    Keyboard.write(10);
  }
}

// ----------------------------------------------------------------------------
// Function to format EEprom
// ----------------------------------------------------------------------------
void FormatEEProm()
{
  byte doflash = 0; 
  for (int i = 873 ; i < 1024; i++)
  {
    EEPROM.write(i, 0);
    doflash++; 
    if (doflash == 10)
    {
      LEDcolor(LEDBlue);
      rgbled.show();

    }
    if (doflash == 20)
    {
      LEDcolor(LEDOff);
      rgbled.show();
      doflash = 0;
    }
  }

  //Encrypt Zero Values...
  doflash = 0;
  for (int i = 0; i <buttoncount - 1; i++)
  {
    for (int z = 0; z < 47; z++){
      users[i].PW[z] = 0;
      users[i].User[z] = 0;
    }

    //rgbled.setPixelColor(0, 0, 5 * i, 150 - (i * 10));
    ctx = aes128_cbc_enc_start(key, iv);
    aes128_cbc_enc_continue(ctx, users[i].PW, 48);
    aes128_cbc_enc_finish(ctx);

    ctx = aes128_cbc_enc_start(key, iv);
    aes128_cbc_enc_continue(ctx, users[i].User, 48);
    aes128_cbc_enc_finish(ctx);
    LEDcolor(LEDBlue);
    rgbled.show();

    EEPROM_writeAnything(i * 97, users[i]);

    LEDcolor(LockLEDcolor);
    rgbled.show();
    delay(20);

  }

  Serial.print("EraseDone");
  Serial.print(DoneMessage);
  password = Password("0000");

  locked = true;
  LEDcolor(LockLEDcolor);
  password.reset();
  byteCount = 0;
}

// ----------------------------------------------------------------------------
// Function to write login/password to EEprom
// ----------------------------------------------------------------------------
void writeUserToEEprom(int id) 
{
  if (startwrite == true)
  {
    //Serial.println("Clear Object...");
    for (int i=0; i <= 47; i++){
      users[id].User[i]=0;
      users[id].PW[i] =0;
    } 
    users[id].enter = false; 
    startwrite =false;
  }	

  gRxBuffer[byteCount]=b;
  byteCount++;

  if (b==UserDoneByte) 
  {
    userdone = true; 
    writeCount = 0;
    /*Serial.print("User ");
     		Serial.print(id+1);
     		Serial.println("Done");*/
    return;
  }

  if (b == PWDoneByte)
  {
    pwdone = true; 
    //Serial.println("PW1Done");
    return;
  }

  if (b == EOTByte)
  {
    Serial.print("WriteUser");
    Serial.print(id+1);
    Serial.print("Name:");
    Serial.print(users[id].User);
    Serial.print(DoneMessage);

    ctx = aes128_cbc_enc_start(key, iv);
    aes128_cbc_enc_continue(ctx, users[id].PW, 48);
    aes128_cbc_enc_finish(ctx);
    ctx = aes128_cbc_enc_start(key, iv);
    aes128_cbc_enc_continue(ctx, users[id].User, 48);
    aes128_cbc_enc_finish(ctx);

    EEPROM_writeAnything(id*97,users[id]);
    byteCount=0;
    return;
  }

  if (userdone == false)
  {					
    users[id].User[writeCount] = b;
    writeCount++;
    return;
  }
  else if (pwdone == false)
  {					
    users[id].PW[writeCount] = b;
    writeCount++;
    return;
  }
  else
  {
    if (b == 1) 
      users[id].enter = true;
    else
      users[id].enter = false;
    return;
  }		

}
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

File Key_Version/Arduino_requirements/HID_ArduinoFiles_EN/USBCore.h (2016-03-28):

// Copyright (c) 2010, Peter Barrett 
/*
** Permission to use, copy, modify, and/or distribute this software for  
** any purpose with or without fee is hereby granted, provided that the  
** above copyright notice and this permission notice appear in all copies.  
**  
** THE SOFTWARE IS PROVIDED "AS IS" AND THE AUTHOR DISCLAIMS ALL  
** WARRANTIES WITH REGARD TO THIS SOFTWARE INCLUDING ALL IMPLIED  
** WARRANTIES OF MERCHANTABILITY AND FITNESS. IN NO EVENT SHALL THE AUTHOR  
** BE LIABLE FOR ANY SPECIAL, DIRECT, INDIRECT, OR CONSEQUENTIAL DAMAGES  
** OR ANY DAMAGES WHATSOEVER RESULTING FROM LOSS OF USE, DATA OR PROFITS,  
** WHETHER IN AN ACTION OF CONTRACT, NEGLIGENCE OR OTHER TORTIOUS ACTION,  
** ARISING OUT OF OR IN CONNECTION WITH THE USE OR PERFORMANCE OF THIS  
** SOFTWARE.    
*/

#ifndef __USBCORE_H__
#define __USBCORE_H__

//	Standard requests
#define GET_STATUS			0
#define CLEAR_FEATURE		1
#define SET_FEATURE			3
#define SET_ADDRESS			5
#define GET_DESCRIPTOR		6
#define SET_DESCRIPTOR		7
#define GET_CONFIGURATION	8
#define SET_CONFIGURATION	9
#define GET_INTERFACE		10
#define SET_INTERFACE		11


// bmRequestType
#define REQUEST_HOSTTODEVICE	0x00
#define REQUEST_DEVICETOHOST	0x80
#define REQUEST_DIRECTION		0x80

#define REQUEST_STANDARD		0x00
#define REQUEST_CLASS			0x20
#define REQUEST_VENDOR			0x40
#define REQUEST_TYPE			0x60

#define REQUEST_DEVICE			0x00
#define REQUEST_INTERFACE		0x01
#define REQUEST_ENDPOINT		0x02
#define REQUEST_OTHER			0x03
#define REQUEST_RECIPIENT		0x03

#define REQUEST_DEVICETOHOST_CLASS_INTERFACE  (REQUEST_DEVICETOHOST + REQUEST_CLASS + REQUEST_INTERFACE)
#define REQUEST_HOSTTODEVICE_CLASS_INTERFACE  (REQUEST_HOSTTODEVICE + REQUEST_CLASS + REQUEST_INTERFACE)

//	Class requests

#define CDC_SET_LINE_CODING			0x20
#define CDC_GET_LINE_CODING			0x21
#define CDC_SET_CONTROL_LINE_STATE	0x22

#define MSC_RESET					0xFF
#define MSC_GET_MAX_LUN				0xFE

#define HID_GET_REPORT				0x01
#define HID_GET_IDLE				0x02
#define HID_GET_PROTOCOL			0x03
#define HID_SET_REPORT				0x09
#define HID_SET_IDLE				0x0A
#define HID_SET_PROTOCOL			0x0B

//	Descriptors

#define USB_DEVICE_DESC_SIZE 18
#define USB_CONFIGUARTION_DESC_SIZE 9
#define USB_INTERFACE_DESC_SIZE 9
#define USB_ENDPOINT_DESC_SIZE 7

#define USB_DEVICE_DESCRIPTOR_TYPE             1
#define USB_CONFIGURATION_DESCRIPTOR_TYPE      2
#define USB_STRING_DESCRIPTOR_TYPE             3
#define USB_INTERFACE_DESCRIPTOR_TYPE          4
#define USB_ENDPOINT_DESCRIPTOR_TYPE           5

#define USB_DEVICE_CLASS_COMMUNICATIONS        0x02
#define USB_DEVICE_CLASS_HUMAN_INTERFACE       0x03
#define USB_DEVICE_CLASS_STORAGE               0x08
#define USB_DEVICE_CLASS_VENDOR_SPECIFIC       0xFF

#define USB_CONFIG_POWERED_MASK                0x40
#define USB_CONFIG_BUS_POWERED                 0x80
#define USB_CONFIG_SELF_POWERED                0xC0
#define USB_CONFIG_REMOTE_WAKEUP               0x20

// bMaxPower in Configuration Descriptor
#define USB_CONFIG_POWER_MA(mA)                ((mA)/2)

// bEndpointAddress in Endpoint Descriptor
#define USB_ENDPOINT_DIRECTION_MASK            0x80
#define USB_ENDPOINT_OUT(addr)                 ((addr) | 0x00)
#define USB_ENDPOINT_IN(addr)                  ((addr) | 0x80)

#define USB_ENDPOINT_TYPE_MASK                 0x03
#define USB_ENDPOINT_TYPE_CONTROL              0x00
#define USB_ENDPOINT_TYPE_ISOCHRONOUS          0x01
#define USB_ENDPOINT_TYPE_BULK                 0x02
#define USB_ENDPOINT_TYPE_INTERRUPT            0x03

#define TOBYTES(x) ((x) & 0xFF),(((x) >> 8) & 0xFF)

#define CDC_V1_10                               0x0110
#define CDC_COMMUNICATION_INTERFACE_CLASS       0x02

#define CDC_CALL_MANAGEMENT                     0x01
#define CDC_ABSTRACT_CONTROL_MODEL              0x02
#define CDC_HEADER                              0x00
#define CDC_ABSTRACT_CONTROL_MANAGEMENT         0x02
#define CDC_UNION                               0x06
#define CDC_CS_INTERFACE                        0x24
#define CDC_CS_ENDPOINT                         0x25
#define CDC_DATA_INTERFACE_CLASS                0x0A

#define MSC_SUBCLASS_SCSI						0x06 
#define MSC_PROTOCOL_BULK_ONLY					0x50 

#define HID_HID_DESCRIPTOR_TYPE					0x21
#define HID_REPORT_DESCRIPTOR_TYPE				0x22
#define HID_PHYSICAL_DESCRIPTOR_TYPE			0x23


//	Device
typedef struct {
	u8 len;				// 18
	u8 dtype;			// 1 USB_DEVICE_DESCRIPTOR_TYPE
	u16 usbVersion;		// 0x200
	u8	deviceClass;
	u8	deviceSubClass;
	u8	deviceProtocol;
	u8	packetSize0;	// Packet 0
	u16	idVendor;
	u16	idProduct;
	u16	deviceVersion;	// 0x100
	u8	iManufacturer;
	u8	iProduct;
	u8	iSerialNumber;
	u8	bNumConfigurations;
} DeviceDescriptor;

//	Config
typedef struct {
	u8	len;			// 9
	u8	dtype;			// 2
	u16 clen;			// total length
	u8	numInterfaces;
	u8	config;
	u8	iconfig;
	u8	attributes;
	u8	maxPower;
} ConfigDescriptor;

//	String

//	Interface
typedef struct
{
	u8 len;		// 9
	u8 dtype;	// 4
	u8 number;
	u8 alternate;
	u8 numEndpoints;
	u8 interfaceClass;
	u8 interfaceSubClass;
	u8 protocol;
	u8 iInterface;
} InterfaceDescriptor;

//	Endpoint
typedef struct
{
	u8 len;		// 7
	u8 dtype;	// 5
	u8 addr;
	u8 attr;
	u16 packetSize;
	u8 interval;
} EndpointDescriptor;

// Interface Association Descriptor
// Used to bind 2 interfaces together in CDC compostite device
typedef struct
{
	u8 len;				// 8
	u8 dtype;			// 11
	u8 firstInterface;
	u8 interfaceCount;
	u8 functionClass;
	u8 funtionSubClass;
	u8 functionProtocol;
	u8 iInterface;
} IADDescriptor;

//	CDC CS interface descriptor
typedef struct
{
	u8 len;		// 5
	u8 dtype;	// 0x24
	u8 subtype;
	u8 d0;
	u8 d1;
} CDCCSInterfaceDescriptor;

typedef struct
{
	u8 len;		// 4
	u8 dtype;	// 0x24
	u8 subtype;
	u8 d0;
} CDCCSInterfaceDescriptor4;

typedef struct 
{
    u8	len;
    u8 	dtype;		// 0x24
    u8 	subtype;	// 1
    u8 	bmCapabilities;
    u8 	bDataInterface;
} CMFunctionalDescriptor;
	
typedef struct 
{
    u8	len;
    u8 	dtype;		// 0x24
    u8 	subtype;	// 1
    u8 	bmCapabilities;
} ACMFunctionalDescriptor;

typedef struct 
{
	//	IAD
	IADDescriptor				iad;	// Only needed on compound device

	//	Control
	InterfaceDescriptor			cif;	// 
	CDCCSInterfaceDescriptor	header;
	CMFunctionalDescriptor		callManagement;			// Call Management
	ACMFunctionalDescriptor		controlManagement;		// ACM
	CDCCSInterfaceDescriptor	functionalDescriptor;	// CDC_UNION
	EndpointDescriptor			cifin;

	//	Data
	InterfaceDescriptor			dif;
	EndpointDescriptor			in;
	EndpointDescriptor			out;
} CDCDescriptor;

typedef struct 
{
	InterfaceDescriptor			msc;
	EndpointDescriptor			in;
	EndpointDescriptor			out;
} MSCDescriptor;

typedef struct
{
	u8 len;			// 9
	u8 dtype;		// 0x21
	u8 addr;
	u8	versionL;	// 0x101
	u8	versionH;	// 0x101
	u8	country;
	u8	desctype;	// 0x22 report
	u8	descLenL;
	u8	descLenH;
} HIDDescDescriptor;

typedef struct 
{
	InterfaceDescriptor			hid;
	HIDDescDescriptor			desc;
	EndpointDescriptor			in;
} HIDDescriptor;
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

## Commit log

2016-03-29 upload schematic
2016-03-29 Add schematic
2018-04-22 create desktop version and adapt main readme
    [main.STL]
2018-04-22 flash led factorization
2018-05-03 Fix Bug on long press
    [HardwarePWManager.ino]
2018-05-13 Update Source_code.ino
    Fix bug on long press
    [Source_code.ino]
2019-04-07 add board files
    [PW-Stick.brd, PW-Stick.sch]

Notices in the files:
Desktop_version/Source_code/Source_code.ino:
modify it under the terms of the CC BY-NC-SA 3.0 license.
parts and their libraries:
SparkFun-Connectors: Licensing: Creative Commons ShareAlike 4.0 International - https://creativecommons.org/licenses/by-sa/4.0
